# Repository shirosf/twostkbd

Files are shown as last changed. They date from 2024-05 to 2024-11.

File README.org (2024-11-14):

* Two-stroke single hand keyboard
** Introduction
This is a following project to [[https://github.com/shirosf/binarykbd][Binary5 keyboard]]
The basic idea of this keyboard is as follows:
+ hit one of 6 keys twice: 36 codes
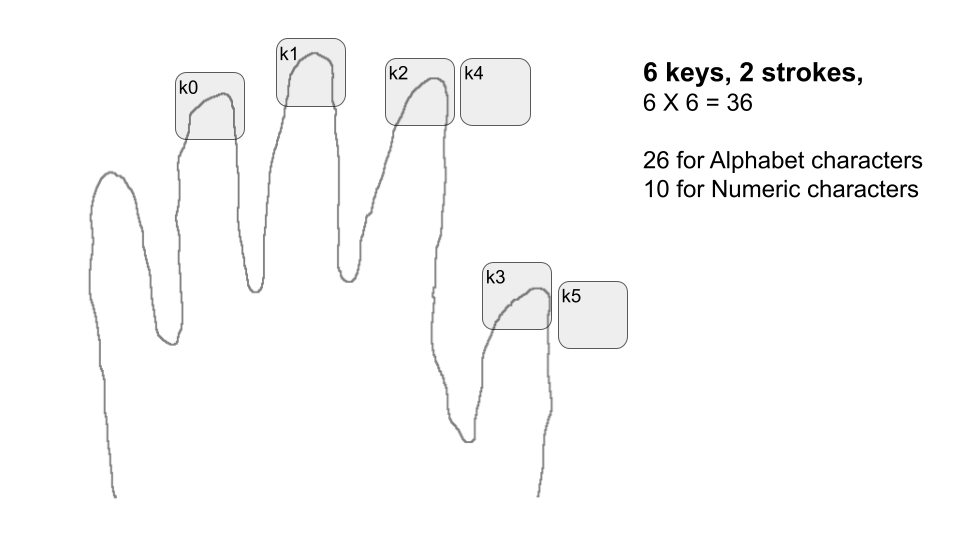
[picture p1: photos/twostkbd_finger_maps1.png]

+ 4 modifiers: 'shift','ctrl','alt', and one more 'ext'
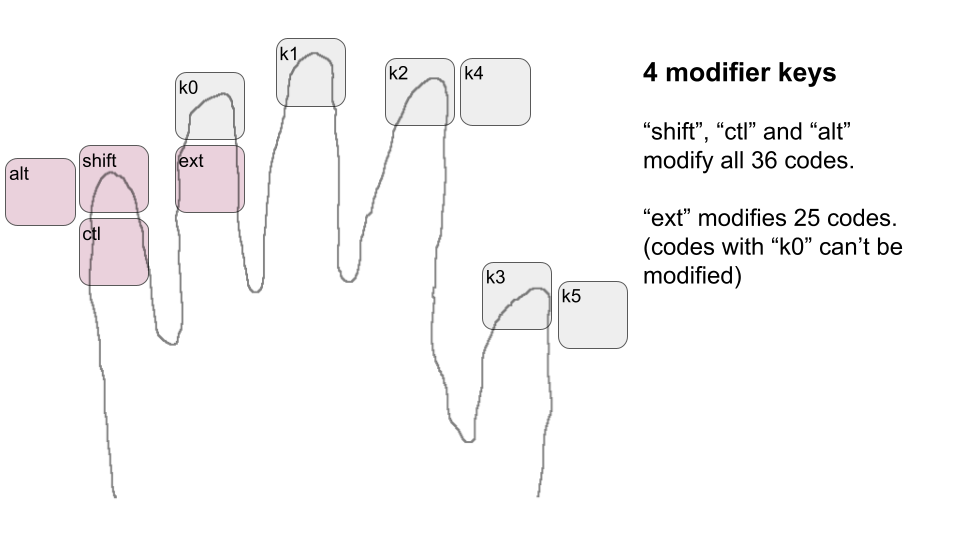
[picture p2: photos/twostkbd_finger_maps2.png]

+ 3 function keys: 'SPACE','BACK SPACE','RETERN'
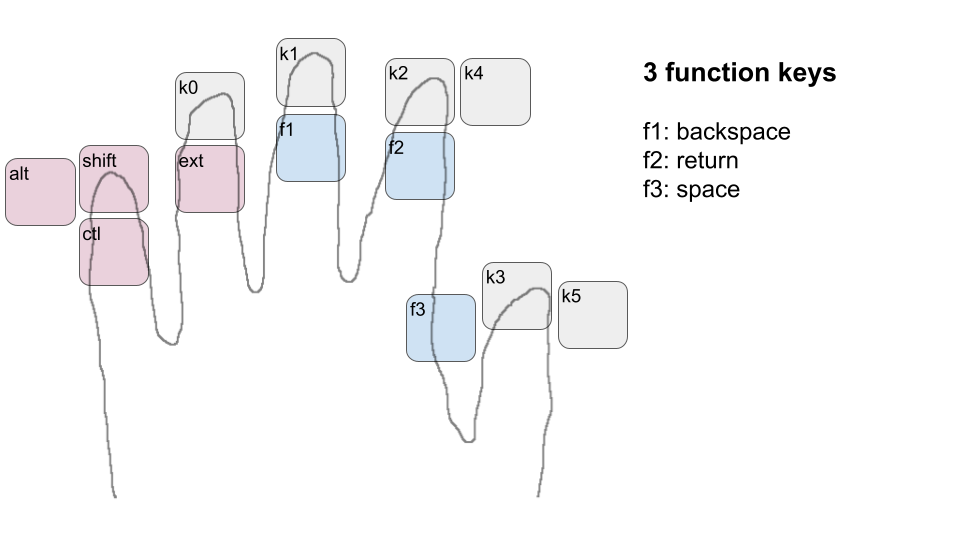
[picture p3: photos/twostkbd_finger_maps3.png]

All key maps can be changed by a configuration file

The total uses 13 keys.
26 of the 36 codes are used for alphabet character codes.
The other 10 are used for numerical character codes.
'ext' modifiers support symbol character codes.

** Hardware
KiCAD schematic and PCB data are in 'pcb' directory.
The HW consists of key switches, LEDs and Raspberry Pi Zero.
The circuits are mostly simple connections between GPIOs and switches.
#+ATTR_LATEX: :width 200px
#+ATTR_HTML: :width 200px
#+CAPTION: 14 keys and Raspberry Pi Zero
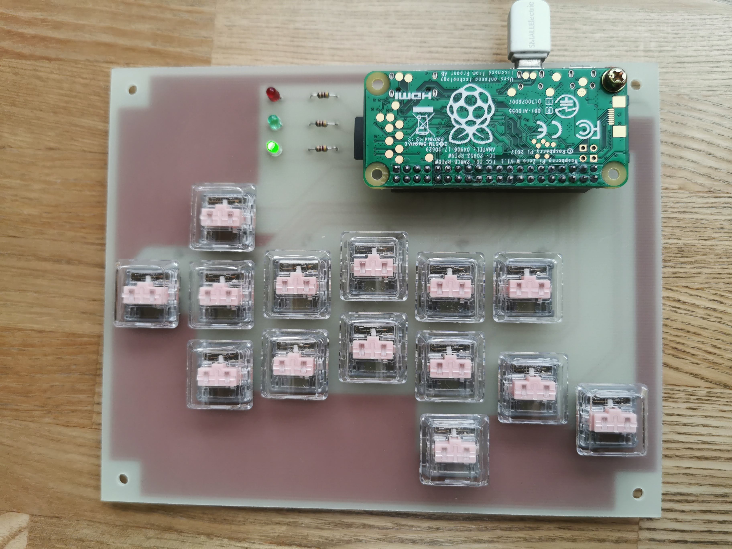
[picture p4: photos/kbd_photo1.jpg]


<2024-09-13 Fri>
Supported "Arduino Nano ESP32" to attach on PiZero connector.
#+ATTR_LATEX: :width 200px
#+ATTR_HTML: :width 200px
#+CAPTION: 13 keys and Arduin Nano ESP32
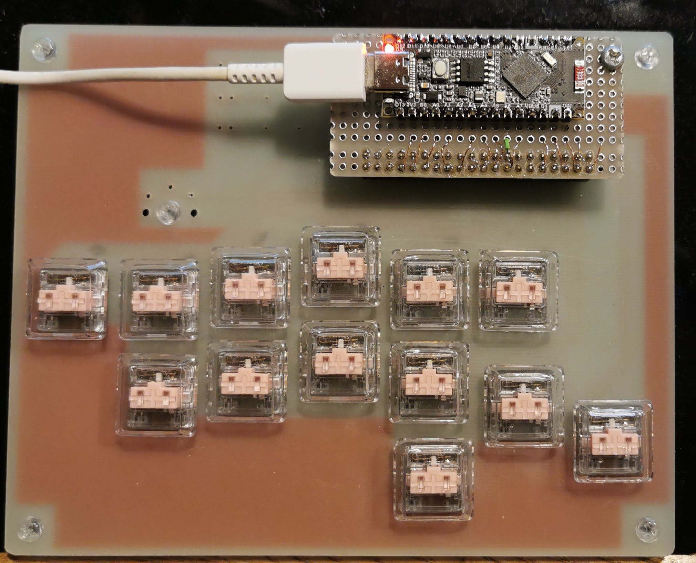
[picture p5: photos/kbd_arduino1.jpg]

It would be better to have both PiZero connector and Arduino Nano
connector on the PCB.
I would update the PCB design at the time of the next PCB order.
Arduino GBIO connections are defined in "key-gpio table" in "config.org"

** Arduino Software
Arduino project directory is "twskbino".
Go to the directory, then edit "Makefile" there to adjust to your hardware.
My Arduino board was an unofficial "esp32-s3" type board; to find out
"FBQN", I chose a looks-close one.
I believe that as long as it is "esp32-s3" type board "FBQN" should be okay.

To build and install from that Makefile, you need to install "arduino-cli"
and "esp32-s3" library.
Once they are ready, "make install" does all the jobs.

People who use IDE need a different way.

The way of configuration is the same as the PiZero Software.
Everything is defined in "config.org".

Arduino Nano has a RGB-LED on the board.
It starts with non-lighting status(R, G, B are all turned off).
'B' is ON when a key is pressed.
'G' is ON when any modifier key is pressed or locked.

** PiZero Software
*** Installation
Copy following 3 files into some directory of Pi Zero.
+ twostkbd.py, create_device.sh, config.org

Using included Makefile, "make sshcopy" copies the files by 'scp'.
It needs 'pizero' defined in ssh config.

*** Run
You go to the directory of the target Pi Zero where 3 files above are copied
by ssh or a local terminal.

At the first time after booting up, 'create_device.sh' needs to be run.
It creates a USB HID device: '/dev/hidg0'.

Once the USB HID device is created, 'twostkbd.py' can run, and it feeds
keyboard events into the device.

*** systemd service
To make the program start automatically at boot time, install "twostkbd.service"
and enable it as follows:
when you copy "twostkbd.py, create_device.sh, config.org" to the target Pi Zero,
you also copy "Makefile, twostkbd.service". Then go to the directory, and run the
following commands:
$ sudo make install
$ sudo make enable_service

When you changed the program or the config file in the working directory,
$ sudo make install
then restart the service again as next:
$ sudo systemctl restart twostkbd.service

*** Configuration
'twostkbd.py' reads 'config.org' file in the working directory.
'config.org' has the following 4 sections:
+ key-gpio table
  Each row defines,
  "schematic switch symbol","GPIO number","key name in this config file"
  Any key switch position can be changed in this table.
  E.G. swapping 'ctrl' and 'shift' in the table swaps the positions of 'ctrl' key
  and 'shift' key.

+ 6-key table
  Each row defines,
  assigned key: alphabet or number.
  '1st key' and '2nd key' combination by number, which is the number part of 'k*' name.
  modified key by the modifier key.
  The most of 'shift', 'alt', 'ctrl' modifier positions are empty.  In those cases the
  modifiers simply add the named modifier bits on the key events.

+ fkey table
  This table defines the function keys: f0 to f3.

+ multikeys table
  When more than 2 keys are pressed at the same time, it functions as "func" column
  defined function.

** License
Unless otherwise explicitly stated,
all files in this project are released under GNU General Public License Version 2.

** Development history
*** <2024-11-15 Fri>
With a half year practice, I come to around 25-WPM level.
And it seems to be saturated and the progress from this point will be very slow.
For some purposes, this keyboard could be useful.
But for my use, which is mostly writing program codes, it can't replace
regular 2-handed keyboards.

I stop this project at this point.

*** <2024-09-14 Sat>
+ Released the Arduino ESP32-S3 software.
PiZero runs a heavy Linux kernel and takes a long time to boot up.
There must be a room to improve by optimization, but I thought it
wouldn't come to my expected level.
With Arduino HW, connecting a USB cable, it becomes ready to use in a second.
Arduino supports a very convenient USBHIDKeyboard library; thanks to it
developing the software was easy.

+ Created a new board which uses "[[http://www.kailh.com/en/Products/Ks/CS/][Kailh Choc Switch]], Red".
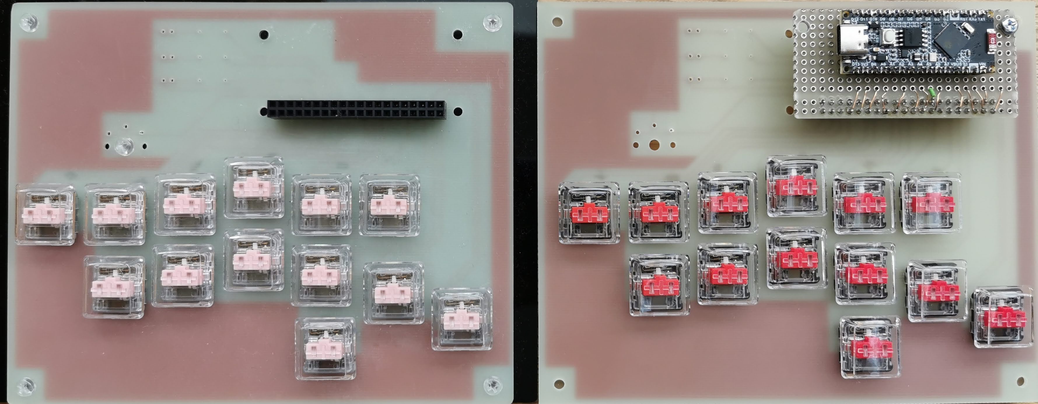
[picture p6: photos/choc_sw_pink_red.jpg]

I've been using "Pink" with 20g operation force.
It was the lightest operation force in what I could find in the market.
Actuary it is a little too light, and I often hit wrong keys inadvertently.
"Red" with 50g is better for that point.
Pursuing faster typing, however, "Pink" would be better.
I'm still wondering which I should use.

*** <2024-08-03 Sat>
Moved TAB to "multikeys table". "k1,k2,k3" is easier than "shift-f2".
"fkey table" modifier functions are all empty, modifier keys are applied on the all.
Changed MULTIKEY_GAP to 50msec from 30msec.

*** <2024-08-02 Fri>
Changed "multikeys table", "up" and "down" are swapped.

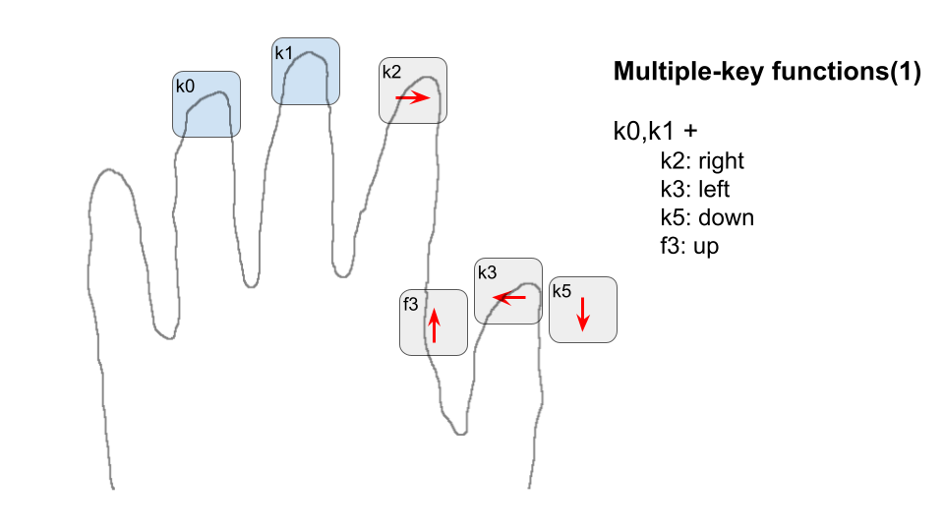
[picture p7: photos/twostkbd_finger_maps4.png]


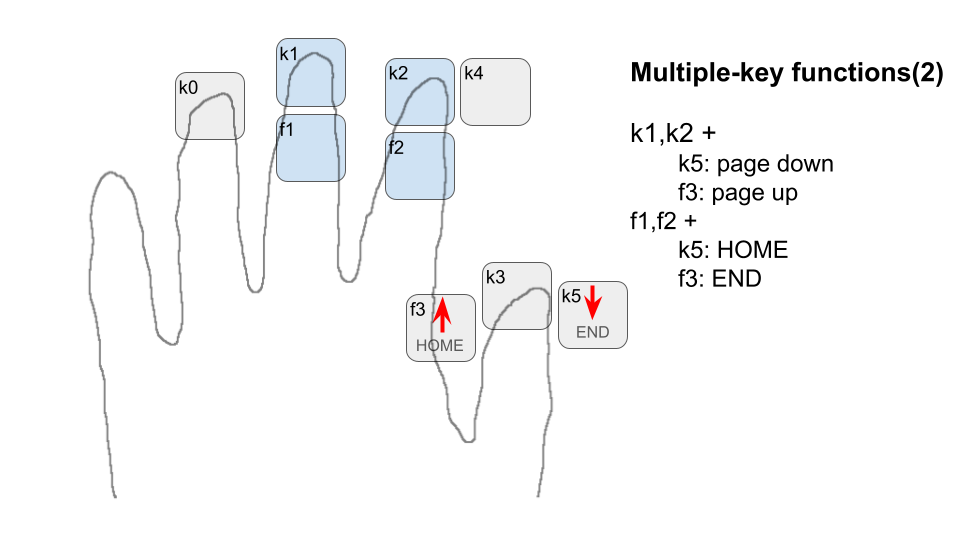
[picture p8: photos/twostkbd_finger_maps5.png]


*** <2024-08-01 Thu>
Refactored the code.
Using "keyqueue", removed multiple timers.
Using "bounce_time" to create Button object, removed the chattering cancellation process.

*** <2024-07-21 Sun>
Tuned "multikeys table" to be convenient for cursor moves.

*** <2024-07-18 Thu>
Removed "fmode table", added "multikeys table" instead.

*** <2024-06-30 Sun>
Published [[https://youtu.be/tp5e6nVgrqI][Youtube Video]].

*** <2024-06-17 Mon>
Modifier keys are difficult to keep holding, especially ALT key.
For a solution, make hitting a modifier key be a locked status for the following
character input.
E.G.
1. hit ALT and release, this locks ALT status
2. input 'x', this becomes ALT-x, and the modifier lock status is released.
When a modifier key is held pressed and a character input happens, the modifier key
is not locked.

*** <2024-06-01 Sat>
Send modifier key events without character key events, so that 'Alt' + 'Mouse click'
type actions can work.

*** <2024-05-25 Sat>
'f0' key is difficult to press. I removed it.
Now, the function keys are 3: 'f1', 'f2' and 'f3'.
'TAB' function is covered by 'shift'+'f2'.

*** <2024-05-14 Tue>
The program basically works okay.
I started practice.

*** <2024-05-10 Fri>
Received PCB

#+OPTIONS: \n:t ^:nil

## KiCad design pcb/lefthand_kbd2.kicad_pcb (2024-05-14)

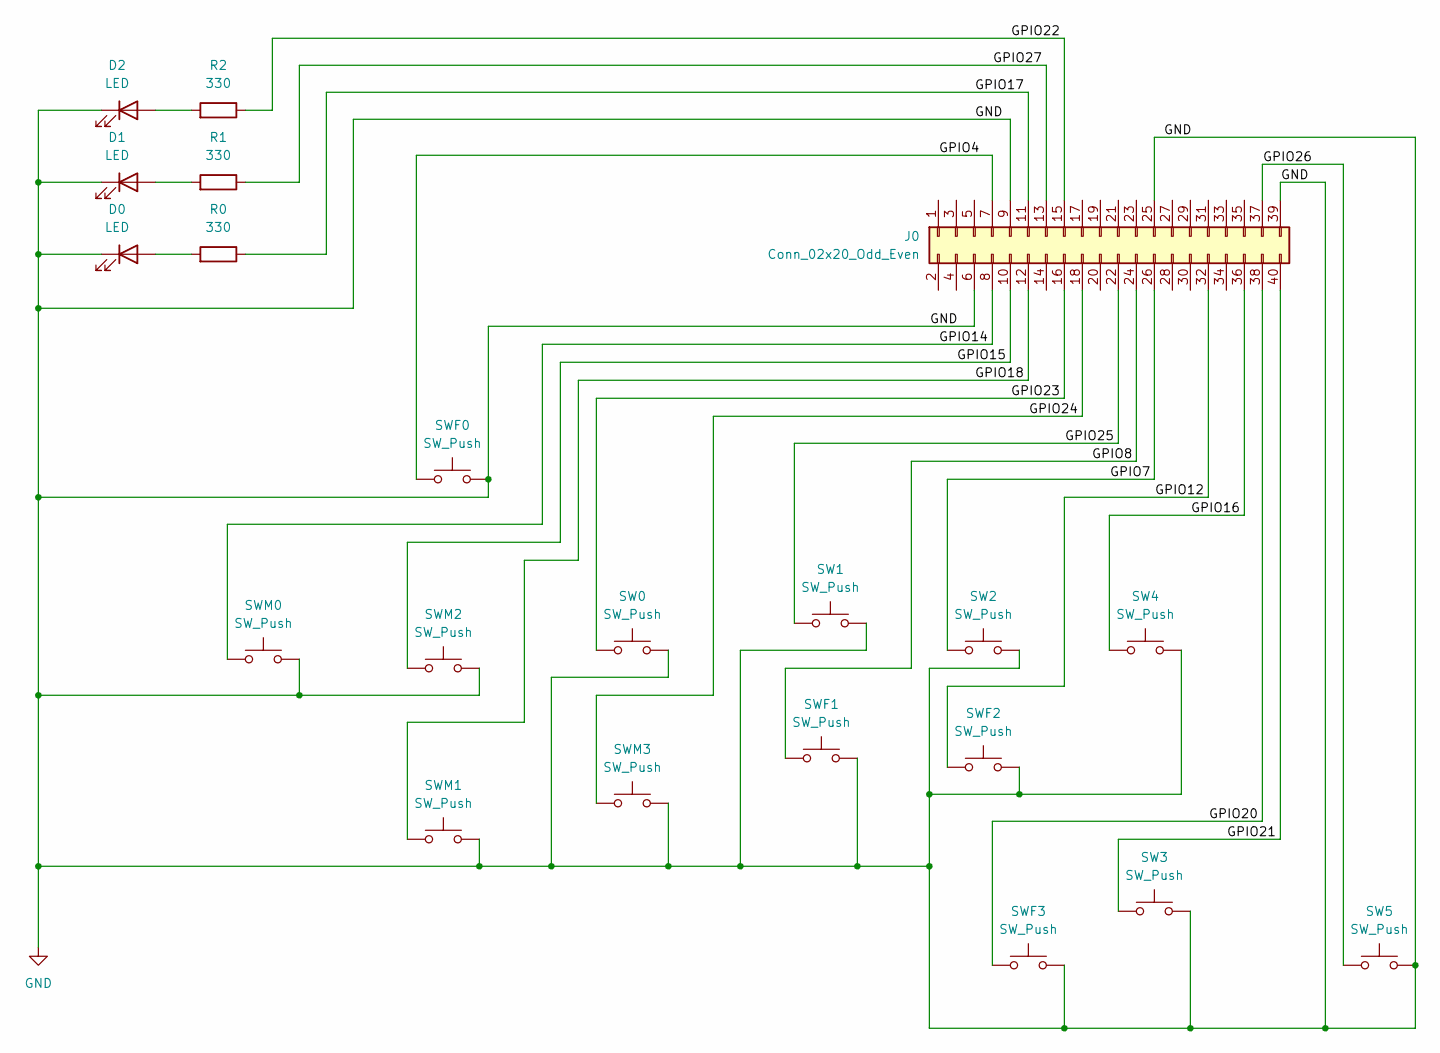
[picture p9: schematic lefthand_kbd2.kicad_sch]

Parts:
D0, D1, D2: LED; D_T-1_P2.54mm_Vertical_AnodeUp
J0: Conn_02x20_Odd_Even; Raspberry_Pi_Zero_Socketed_THT_FaceDown_MountingHoles
R0, R1, R2: 330; R_Axial_DIN0204_L3.6mm_D1.6mm_P7.62mm_Horizontal
SW0, SW1, SW2, SW3, SW4, SW5: SW_Push; Kailh_Choc
SWF0, SWF1, SWF2, SWF3: SW_Push; Kailh_Choc
SWM0, SWM1, SWM2, SWM3: SW_Push; Kailh_Choc

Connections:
/GPIO4: J0.7, SWF0.1
/GPIO7: J0.26, SW2.1
/GPIO8: J0.24, SWF1.1
/GPIO12: J0.32, SWF2.1
/GPIO14: J0.8, SWM0.1
/GPIO15: J0.10, SWM2.1
/GPIO16: J0.36, SW4.1
/GPIO17: J0.11, R0.1
/GPIO18: J0.12, SWM1.1
/GPIO20: J0.38, SWF3.1
/GPIO21: J0.40, SW3.1
/GPIO22: J0.15, R2.1
/GPIO23: J0.16, SW0.1
/GPIO24: J0.18, SWM3.1
/GPIO25: J0.22, SW1.1
/GPIO26: J0.37, SW5.1
/GPIO27: J0.13, R1.1
GND: D0.1 (K), D1.1 (K), D2.1 (K), J0.6, J0.9, J0.25, J0.39, SW0.2, SW1.2, SW2.2, SW3.2, SW4.2, SW5.2, SWF0.2, SWF1.2, SWF2.2, SWF3.2, SWM0.2, SWM1.2, SWM2.2, SWM3.2
unnamed: D0.2 (A), R0.2
unnamed: D1.2 (A), R1.2
unnamed: D2.2 (A), R2.2

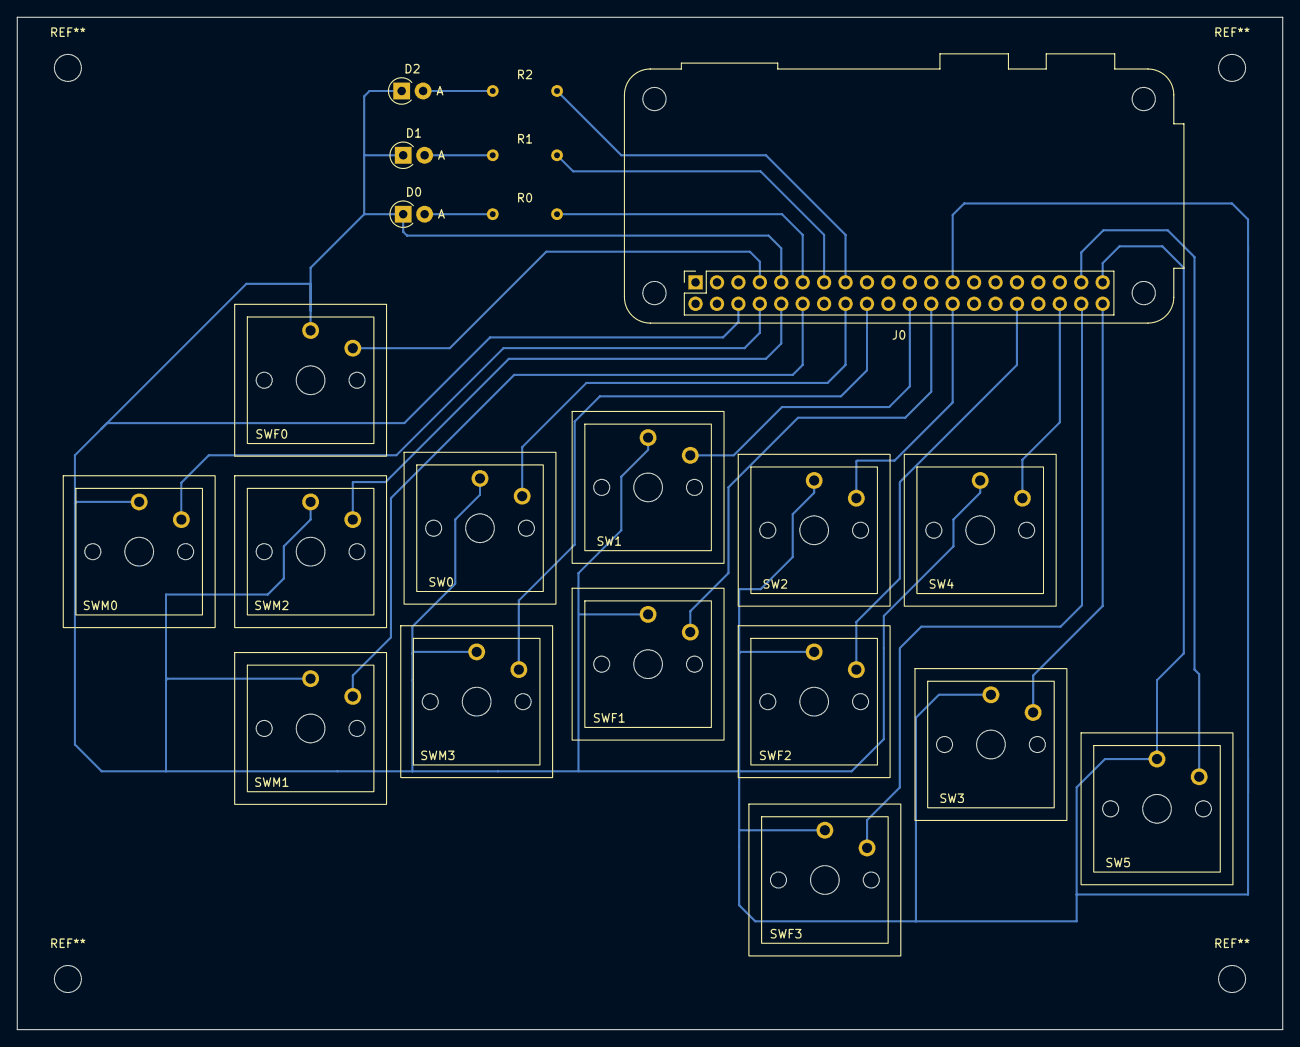
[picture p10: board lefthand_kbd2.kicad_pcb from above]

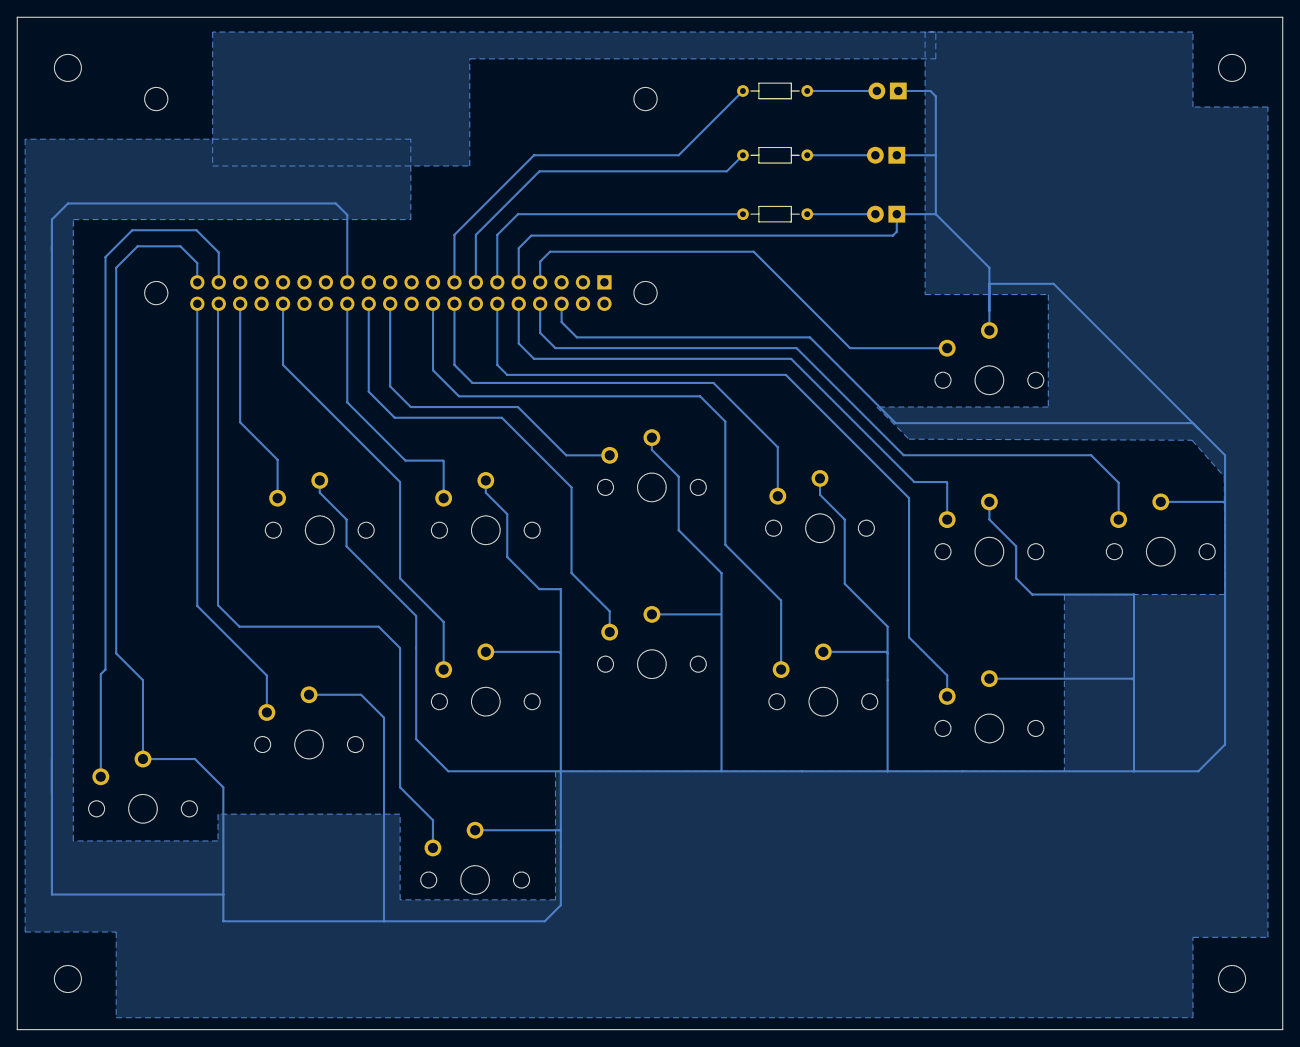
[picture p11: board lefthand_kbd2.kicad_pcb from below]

Board: 2 copper layers, 150.0 x 120.0 mm, 21 parts (3 on the bottom side), 21 nets.

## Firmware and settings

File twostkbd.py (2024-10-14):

#!/usr/bin/env python3
# -*- coding: utf-8 -*-
#
# Copyright (C) 2024 Shiro Ninomiya
#
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
import logging
import time
import threading
try:
    from gpiozero import Button, LED
except:
    print("not running on PiZero")

logger=logging.getLogger('twostkbd')
logger.setLevel(logging.DEBUG)

class KbdConfig():
    flabels=("alt","ctrl","shift","ext","k0","k1","k2","k3","k4","k5","f0","f1","f2","f3")
    mnames=("shift", "alt", "ctrl", "ext")
    def get_keygpio_table(self, items):
        if len(items)<5: return 0
        try:
            kname=items[1].strip()
            if kname=="kname": return 0
            gpn=int(items[2])
            if gpn<0 or gpn>27: raise ValueError
            self.btgpios[kname]=gpn
            self.argpios[kname]=items[3].strip()
        except ValueError:
            logger.error("gpio msut be a number in 0 to 27, %s" % str(items))
            return -1
        return 0

    def get_skey_table(self, items):
        if len(items)<10: return 0
        try:
            item1=items[1].strip()
            if item1=="": return 0
            if item1=='No.': return 0
            index=int(item1)
            if index<0 or index>35: raise ValueError
        except ValueError:
            logger.error("'No.' item msut be a number in 0 to 35")
            return -1
        try:
            key=items[2].strip()
            firstkey=items[3].strip()
            secondkey=items[4].strip()
            mkeys={}
            for i in range(4):
                mkeys[self.mnames[i]]=items[5+i].strip()
        except:
            logger.error("invalid value in 6-key table")
            return -1
        self.skeytable[index]={"key":key, "1st":firstkey, "2nd":secondkey, "mkeys":mkeys}
        return 0

    def get_fkey_table(self, items):
        if len(items)<8: return 0
        try:
            item1=items[1].strip()
            if item1=="": return 0
            if item1=='f.key': return 0
            index=int(item1)
            if index<0 or index>3: raise ValueError
        except ValueError:
            logger.error("'f.key' item msut be a number in 0 to 3")
            return -1
        try:
            func=items[2].strip()
            mfuncs={}
            for i in range(4):
                mfuncs[self.mnames[i]]=items[3+i].strip()
        except:
            logger.error("invalid value in fkey table")
            return -1
        self.fkeytable[index]={"func":func, "mfuncs":mfuncs}
        return 0

    def get_multikeys_table(self, items):
        if len(items)<4: return 0
        item1=items[1].strip()
        if item1=="": return 0
        if item1=='func': return 0
        multikeys=items[2].strip().split(",")
        v=0
        for mk in multikeys:
            v|=1<<self.btgpios[mk]
        self.multikeystable[v]=item1
        self.mkeytable.append([item1]+multikeys)
        return 0

    def readconf(self, conffile: str="config.org") -> int:
        inf=open(conffile, "r")
        state=0
        self.skeytable=[None]*36
        self.fkeytable=[None]*4
        self.multikeystable={}
        self.mkeytable=[]
        self.btgpios={}
        self.argpios={}
        while True:
            keydef={}
            line=inf.readline()
            if line=='': break
            if state==0:
                if line.find("key-gpio table")>0:
                    state=1
                if line.find("6-key table")>0:
                    state=2
                if line.find("fkey table")>0:
                    state=3
                if line.find("multikeys table")>0:
                    state=4
                continue
            if line[0]!='|':
                state=0
                continue
            items=line.split('|')
            if state==1:
                if self.get_keygpio_table(items)!=0: return -1
            if state==2:
                if self.get_skey_table(items)!=0: return -1
            if state==3:
                if self.get_fkey_table(items)!=0: return -1
            if state==4:
                if self.get_multikeys_table(items)!=0: return -1
        inf.close()
        return 0

class KbdDevice():
    BOUNCE_GUARD_SEC=0.01
    MULTIKEY_GAP_NS=50000000
    def __init__(self):
        self.config=KbdConfig()
        if self.config.readconf()!=0:
            logger.error("can't read 'config.org'")
            return
        self.buttons={}
        ledgpios={"LED0":17, "LED1":27, "LED2":22}
        self.leds={"LED0":None, "LED1":None, "LED2":None}
        tsns=time.time_ns()
        for l in self.config.btgpios.keys():
            bt=Button(self.config.btgpios[l], bounce_time=KbdDevice.BOUNCE_GUARD_SEC)
            self.buttons[bt]={"kname":l, "ts":time.time_ns(), "state":0, "ontimer":None,
                              "offtimer":None}
            bt.when_pressed=self.on_pressed
            bt.when_released=self.on_released
        for l in self.leds.keys():
            self.leds[l]=LED(ledgpios[l])
        self.multikey_timer=None
        self.multikey_pressedv=0
        self.modkeys={"shift":False, "alt":False, "ctrl":False, "ext":False}
        self.modkeys_lock={"shift":False, "alt":False, "ctrl":False, "ext":False}
        self.leds["LED0"].on()
        self.modifiers={'RightGUI':(1<<7), 'RightAlt':(1<<6), 'RightShift':(1<<5),
                        'RightCtl':(1<<4), 'LeftGui':(1<<3), 'LeftAlt':(1<<2),
                        'LeftShift':(1<<1), 'LeftCtr':(1<<0)}
        self.devicefd=open("/dev/hidg0", "w")
        self.print_skeytable()
        self.keyqueue=[]
        self.last_write=None

    def print_skeytable(self):
        fhelp={"0":"r ","1":"m ", "2":"i ", "3":"t ", "4":"ir", "5":"tr"}
        for sk in self.config.skeytable:
            skm0=sk["mkeys"]["shift"]
            if not skm0:
                skm0=sk["key"].upper()
            elif skm0=="VBAR":
                skm0="|"
            print("%s(%s)-%s(%s): %s, %s, %s" % ( sk["1st"], fhelp[sk["1st"]],
                                                  sk["2nd"], fhelp[sk["2nd"]],
                                                  sk["key"], skm0, sk["mkeys"]["ext"]))

    def close(self):
        self.devicefd.close()
        for bt in self.buttons.keys():
            bt.close()
        for led in self.leds.values():
            led.close()

    def scancode(self, key: str, nomod: bool = False) -> tuple[int, int]:
        scodes={
            '0':(0x27,0,0),
            'RET':(0x28,0,0),
            'ESC':(0x29,0,0),
            'BS':(0x2a,0,0),
            'TAB':(0x2b,0,0),
            'SP':(0x2c,0,0),
            '-':(0x2d,0,0),
            '=':(0x2e,0,0),
            '[':(0x2f,0,0),
            ']':(0x30,0,0),
            '\\':(0x31,0,0),
            ';':(0x33,0,0),
            "'":(0x34,0,0),
            '`':(0x35,0,0),
            ',':(0x36,0,0),
            '.':(0x37,0,0),
            '/':(0x38,0,0),
            'F1':(0x3a,0,0),
            'F2':(0x3b,0,0),
            'F3':(0x3c,0,0),
            'F4':(0x3d,0,0),
            'F5':(0x3e,0,0),
            'F6':(0x3f,0,0),
            'F7':(0x40,0,0),
            'F8':(0x41,0,0),
            'F9':(0x42,0,0),
            'F10':(0x43,0,0),
            'F11':(0x44,0,0),
            'F12':(0x45,0,0),
            'HOME':(0x4a,0,self.modifiers['LeftCtr']),
            'PUP':(0x4b,0,self.modifiers['LeftAlt']),
            'DEL':(0x4c,0,self.modifiers['LeftCtr']),
            'CSDEL':(0x4c,self.modifiers['LeftShift']|self.modifiers['LeftCtr'],0),
            'END':(0x4d,0,self.modifiers['LeftCtr']),
            'PDOWN':(0x4e,0,self.modifiers['LeftCtr']),
            'RIGHT':(0x4f,0,self.modifiers['LeftCtr']),
            'CRIGHT':(0x4f,self.modifiers['LeftCtr'],self.modifiers['LeftAlt']),
            'LEFT':(0x50,0,self.modifiers['LeftCtr']),
            'CLEFT':(0x50,self.modifiers['LeftCtr'],self.modifiers['LeftAlt']),
            'DOWN':(0x51,0,self.modifiers['LeftCtr']),
            'UP':(0x52,0,self.modifiers['LeftCtr']),
            'COPY':(ord('c')-ord('a')+4,self.modifiers['LeftCtr'],0),
            'PASTE':(ord('v')-ord('a')+4,self.modifiers['LeftCtr'],0),
            'CHOME':(0x4a,self.modifiers['LeftCtr'],0),
            'CEND':(0x4d,self.modifiers['LeftCtr'],0),
            'CTAB':(0x2b,self.modifiers['LeftCtr'],0),
            'SSP':(0x2c,self.modifiers['LeftShift'],0),
            'SRET':(0x28,self.modifiers['LeftShift'],0),
            'SBS':(0x2a,self.modifiers['LeftShift'],0),
            'STAB':(0x2b,self.modifiers['LeftShift'],0),
            'CTLX':(ord('x')-ord('a')+0x04,self.modifiers['LeftCtr'],0),
            'CTLC':(ord('c')-ord('a')+0x04,self.modifiers['LeftCtr'],0),
            'CTLV':(ord('v')-ord('a')+0x04,self.modifiers['LeftCtr'],0),
            'CTLF':(ord('f')-ord('a')+0x04,self.modifiers['LeftCtr'],0),
            'CTLY':(ord('y')-ord('a')+0x04,self.modifiers['LeftCtr'],0),
            'CTLZ':(ord('z')-ord('a')+0x04,self.modifiers['LeftCtr'],0),
            'CTLG':(ord('g')-ord('a')+0x04,self.modifiers['LeftCtr'],0),
            'CTL/':(0x38,self.modifiers['LeftCtr'],0),
            'ALTX':(ord('x')-ord('a')+0x04,self.modifiers['LeftAlt'],0),
            'ALTW':(ord('w')-ord('a')+0x04,self.modifiers['LeftAlt'],0),
            '!':(0x1e,self.modifiers['LeftShift'],0),
            '@':(0x1f,self.modifiers['LeftShift'],0),
            '#':(0x20,self.modifiers['LeftShift'],0),
            '$':(0x21,self.modifiers['LeftShift'],0),
            '%':(0x22,self.modifiers['LeftShift'],0),
            '^':(0x23,self.modifiers['LeftShift'],0),
            '*':(0x25,self.modifiers['LeftShift'],0),
            '&':(0x24,self.modifiers['LeftShift'],0),
            '(':(0x26,self.modifiers['LeftShift'],0),
            ')':(0x27,self.modifiers['LeftShift'],0),
            '_':(0x2d,self.modifiers['LeftShift'],0),
            '+':(0x2e,self.modifiers['LeftShift'],0),
            '{':(0x2f,self.modifiers['LeftShift'],0),
            '}':(0x30,self.modifiers['LeftShift'],0),
            'VBAR':(0x32,self.modifiers['LeftShift'],0),
            ':':(0x33,self.modifiers['LeftShift'],0),
            '"':(0x34,self.modifiers['LeftShift'],0),
            '~':(0x35,self.modifiers['LeftShift'],0),
            '<':(0x36,self.modifiers['LeftShift'],0),
            '>':(0x37,self.modifiers['LeftShift'],0),
            '?':(0x38,self.modifiers['LeftShift'],0),
        }

        mbits=0
        if not nomod:
            if self.modkeys["shift"]:
                mbits|=self.modifiers['LeftShift']
            if self.modkeys["alt"]:
                mbits|=self.modifiers['LeftAlt']
            if self.modkeys["ctrl"]:
                mbits|=self.modifiers['LeftCtr']

        if len(key)==1:
            if key>='a' and key<='z':
                return (ord(key)-ord('a')+0x04, mbits)
            if key>='1' and key<='9':
                return (ord(key)-ord('1')+0x1e, mbits)
        elif len(key)==0:
            return (0, mbits)

        mbits|=scodes[key][1]
        mbits&=~scodes[key][2]
        return (scodes[key][0], mbits)

    def on_pressed(self, bt) -> None:
        if self.multikey_timer: self.multikey_timer.cancel()
        self.multikey_timer=None
        tsns=time.time_ns()
        self.keyqueue.append((bt,tsns))
        self.leds["LED1"].on()
        if self.proc_keyqueue(): return
        self.multikey_timer=threading.Timer(KbdDevice.MULTIKEY_GAP_NS/1E9,
                                            self.proc_multikey_timer)
        self.multikey_timer.start()

    def proc_multikey_timer(self):
        tsns=time.time_ns()
        self.keyqueue.append((None,tsns))
        self.proc_keyqueue()

    # return True when the next press must follow after this
    def proc_keyqueue(self) -> bool:
        res=True
        ki=0
        self.holding_2keys=False
        while(len(self.keyqueue)>ki):
            bt,tsns=self.keyqueue[ki]
            if bt==None:
                ki=self.proc_gapnext(ki)
                res=True
                continue
            kname=self.buttons[bt]["kname"]
            if len(kname)>2:
                # pushed key is a mod key
                self.on_mod_pressed(bt, kname)
                self.keyqueue.pop(ki)
                res=True
                continue
            if ki==0 or self.check_possible_multikeys(ki+1)!=0:
                # "queue top" or "more keys can be expected". go next in the queue
                res=False
                ki+=1
                continue
            # process upto this key in the queue.
            self.proc_stroks(ki+1)
            self.holding_2keys=False
            ki=0
            res=True
        return res

    # get this when Timer expired "None key" come to the queue top.
    # it means the time gap exists keys beofre this "None key"
    def proc_gapnext(self, ki: int):
        self.keyqueue.pop(ki)
        if ki==2:
            dts=self.keyqueue[1][1]-self.keyqueue[0][1]
            if dts<KbdDevice.MULTIKEY_GAP_NS:
                if self.check_possible_multikeys(ki)!=0:
                    # holding 2 keys, 3rd key may be coming. Wait a next key.
                    self.holding_2keys=True
                    return ki
        if ki>1:
            self.proc_stroks(ki) # multiple keys with (0 to ki-1), pop inside the function
            self.holding_2keys=False
            return 0
        if ki==1:
            bt0=self.keyqueue[0][0]
            if self.buttons[bt0]["kname"][0]=="f":
                self.proc_stroks(ki) # process a func key
                return 0
        return ki

    def check_possible_multikeys(self, ki: int, exact=False) -> int:
        if ki==0:
            if self.keyqueue[0][0]["kname"][0]=="k": return 1
            # it must be "f" key
            return 0
        # check with multikeystable
        mkbits=0
        skip_zero=self.keyqueue[1][1]-self.keyqueue[0][1] > \
            KbdDevice.MULTIKEY_GAP_NS
        for i,(bt,tsns) in enumerate(self.keyqueue):
            if i==ki: break
            if bt==None: continue
            if i==0 and skip_zero: continue
            kname=self.buttons[bt]["kname"]
            kbit=1<<self.config.btgpios[kname]
            if ki==2 and mkbits==kbit:
                # the same key twice
                return 0
            mkbits|=kbit
        for mkv in self.config.multikeystable.keys():
            if exact:
                if mkv == mkbits:
                    if skip_zero: self.keyqueue.pop(0)
                    return mkv
            else:
                if (mkbits & mkv) == mkbits: return 1
        return 0

    def proc_stroks(self, ki: int) -> None:
        rk0=None
        if ki>2:
            mkv=self.check_possible_multikeys(ki, exact=True)
            if not mkv:
                for i in range(ki): self.keyqueue.pop(0)
                self.multikey_pressedv=0
                return
            self.on_multikeys_pressed(mkv)
            return
        or_pressed=False
        for i in range(ki):
            bt, tsns=self.keyqueue.pop(0)
            or_pressed|=bt.is_pressed
            kname=self.buttons[bt]["kname"]
            if kname[0]=="f":
                if rk0!=None:
                    # "f" comes after the first "k". It is a cancel signal
                    rk0=None
                    continue
                self.on_fkey_pressed(bt, kname)
                if not or_pressed: self.clear_devicefd()
                continue
            if kname[0]=="k":
                if rk0!=None:
                    self.on_rkey_pressed(rk0, bt)
                    if not or_pressed: self.clear_devicefd()
                    rk0=None
                    continue
                rk0=bt
                continue

    def on_mod_pressed(self, bt, kname: str) -> None:
        if self.modkeys_lock[kname]:
            self.modkeys_lock[kname]=False
            return
        self.modkeys_lock[kname]=True
        self.leds["LED2"].on()
        self.modkeys[kname]=True
        self.hidevent_pressed(kname, "mod")

    def on_fkey_pressed(self, bt, kname: str) -> None:
        self.hidevent_pressed(kname, "func")

    def on_rkey_pressed(self, bt0, bt) -> None:
        kname0=self.buttons[bt0]["kname"]
        kname=self.buttons[bt]["kname"]
        self.hidevent_pressed(kname, "reg", kname0)

    def on_multikeys_pressed(self, mkv:int) -> None:
        kname=self.config.multikeystable[mkv]
        self.hidevent_pressed(kname, "mult")
        self.multikey_pressedv=mkv

    def hidevent_pressed(self, kname: str, mode: str, kname0: str = 0):
        scode=bytearray(b"\0\0\0\0\0\0\0\0")
        if mode=="reg":
            inkey=self.inkey_rk(kname0[1], kname[1])
            self.modkeys_unlock()
        elif mode=="mod":
            inkey=self.scancode('')
        elif mode=="func":
            inkey=self.inkey_fkey(kname[1])
            self.modkeys_unlock()
        elif mode=="mult":
            # only "TAB" uses modifiers
            nomod=False if kname=="TAB" else True
            inkey=self.scancode(kname, nomod=nomod)
            self.modkeys_unlock()
        else:
            return
        if inkey==None: return
        scode[0]=inkey[1]
        scode[2]=inkey[0]
        self.last_write=scode.decode("utf-8")
        self.devicefd.write(self.last_write)
        self.devicefd.flush()

    def inkey_rk(self, kn1, kn2):
        for i in range(36):
            sktable=self.config.skeytable[i]
            if sktable["1st"]!=kn1 or \
               sktable["2nd"]!=kn2:
                continue
            logger.debug("press %s,%d,%d,%d,%d" % (sktable["key"],
                                                   self.modkeys["shift"],self.modkeys["alt"],
                                                   self.modkeys["ctrl"],self.modkeys["ext"]))
            if self.modkeys["ext"] and sktable["mkeys"]["ext"]:
                return self.scancode(sktable["mkeys"]["ext"])
            elif self.modkeys["shift"] and sktable["mkeys"]["shift"]:
                return self.scancode(sktable["mkeys"]["shift"])
            else:
                return self.scancode(sktable["key"])
        else:
            return None

    def inkey_fkey(self, kn):
        fktable=self.config.fkeytable[int(kn)]
        nomod=False
        for mn in KbdConfig.mnames:
            if self.modkeys[mn]:
                fk=fktable["mfuncs"][mn]
                if fk:
                    nomod=True
                    break
        else:
            fk=fktable["func"]
        if not fk: return None
        logger.debug("press %s,%d,%d,%d,%d" % (fk,
                                               self.modkeys["shift"],self.modkeys["alt"],
                                               self.modkeys["ctrl"],self.modkeys["ext"]))
        return self.scancode(fk, nomod=nomod)

    def all_modkeys_off(self) -> bool:
        return not (self.modkeys["shift"] or self.modkeys["alt"] or \
                    self.modkeys["ctrl"] or self.modkeys["ext"])

    def modkeys_unlock(self) -> None:
        for bt,btv in self.buttons.items():
            if btv["kname"][0]=='k' or btv["kname"][0]=='f': continue
            if self.modkeys_lock[btv["kname"]]:
                self.modkeys_lock[btv["kname"]]=False
                if not bt.is_pressed:
                    self.modkeys[btv["kname"]]=False
                    if self.all_modkeys_off(): self.leds["LED2"].off()

    def on_released(self, bt) -> None:
        kname=self.buttons[bt]["kname"]
        if self.multikey_pressedv!=0:
            self.clear_multikey_in_queue(kname)
            return self.clear_devicefd()
        if len(kname)>2:
            # release a mod key
            if self.modkeys_lock[kname]: return
            self.modkeys_unlock()
            self.modkeys[kname]=False
            if self.all_modkeys_off(): self.leds["LED2"].off()
            return self.clear_devicefd()
        if kname[0]=="k":
            # release a regular key
            if self.holding_2keys:
                self.proc_stroks(2)
                self.holding_2keys=False
        return self.clear_devicefd()

    def clear_multikey_in_queue(self, kname) -> None:
        for (bt,tsns) in self.keyqueue:
            qkname=self.buttons[bt]["kname"]
            if kname!=qkname: continue
            self.keyqueue.remove((bt,tsns))
            mkbit=1<<self.config.btgpios[kname]
            self.multikey_pressedv&=~mkbit
            if self.multikey_pressedv==0:
                self.modkeys_unlock()
            return

    def clear_devicefd(self):
        if len(self.keyqueue)==0:
            self.leds["LED1"].off()
        scode=bytearray(b"\0\0\0\0\0\0\0\0")
        inkey_m=self.scancode('')
        scode[0]=inkey_m[1]
        nwd=scode.decode("utf-8")
        if self.last_write!=nwd:
            self.last_write=nwd
            self.devicefd.write(self.last_write)
            self.devicefd.flush()

if __name__ == '__main__':
    kbd = KbdDevice()
    while True:
        try:
            threading.Event().wait()
        except:
            break
    kbd.close()

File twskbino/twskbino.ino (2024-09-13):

#ifndef ARDUINO_USB_MODE
#error This ESP32 SoC has no Native USB interface
#elif ARDUINO_USB_MODE == 1
#warning This sketch should be used when USB is in OTG mode
void setup() {}
void loop() {}
#else

#include "USB.h"
#include "USBHIDKeyboard.h"
#include <soc/gpio_reg.h>
#include "twskb.hpp"

#define LED_RED 46
#define LED_GREEN 0
#define LED_BLUE 45

USBHIDKeyboard Keyboard;


Twskbd *twkd;

struct kbdio_data {
	unsigned char key_gpios[13];
	unsigned char keybit_index[32];
	unsigned long keys_mask;
	unsigned long gpd;
	unsigned long *gpdp;
	unsigned long ugpdp;
};

KbdInOut::KbdInOut(void)
{
	int i;
	unsigned char kbi[13]=KEY_GPIO_LIST;
	kbdiod=(struct kbdio_data*)malloc(sizeof(struct kbdio_data));
	memset(kbdiod, 0, sizeof(struct kbdio_data));
	kbdiod->gpdp=(unsigned long *)GPIO_IN_REG;
	memcpy(kbdiod->key_gpios, kbi, 13);
	memset(kbdiod->keybit_index, 0xff, sizeof(kbdiod->keybit_index));
	for(i=0;i<13;i++){
		pinMode(kbdiod->key_gpios[i], INPUT_PULLUP);
		kbdiod->keys_mask|=(1<<kbdiod->key_gpios[i]);
		kbdiod->keybit_index[kbdiod->key_gpios[i]]=i;
	}
	kbdiod->gpd=*kbdiod->gpdp & kbdiod->keys_mask;
	kbdiod->ugpdp=0;

	pinMode(LED_RED, OUTPUT);
	pinMode(LED_GREEN, OUTPUT);
	pinMode(LED_BLUE, OUTPUT);
	Keyboard.begin();
	USB.begin();
}

KbdInOut::~KbdInOut(void)
{
	free(kbdiod);
}

void KbdInOut::print_kd(KeyFifo::key_fifo_data_t *kd)
{
	char pbuf[4];
	if(kd->pressed){
		sprintf(pbuf, "%d+", kd->ki);
	}else{
		sprintf(pbuf, "%d-", kd->ki);
	}
	Keyboard.print(pbuf);
}

void KbdInOut::set_rgb_led(rgb_color_index_t ci)
{
	digitalWrite(LED_RED, HIGH);
	digitalWrite(LED_GREEN, HIGH);
	digitalWrite(LED_BLUE, HIGH);
	switch(ci){
	case RGB_COLOR_BLACK:
		return;
	case RGB_COLOR_RED:
		digitalWrite(LED_RED, LOW);
		return;
	case RGB_COLOR_GREEN:
		digitalWrite(LED_GREEN, LOW);
		return;
	case RGB_COLOR_BLUE:
		digitalWrite(LED_BLUE, LOW);
		return;
	case RGB_COLOR_YELLOW:
		digitalWrite(LED_RED, LOW);
		digitalWrite(LED_GREEN, LOW);
		return;
	case RGB_COLOR_CYAN:
		digitalWrite(LED_GREEN, LOW);
		digitalWrite(LED_BLUE, LOW);
		return;
	case RGB_COLOR_MAGENTA:
		digitalWrite(LED_RED, LOW);
		digitalWrite(LED_BLUE, LOW);
		return;
	case RGB_COLOR_WHITE:
		digitalWrite(LED_RED, LOW);
		digitalWrite(LED_GREEN, LOW);
		digitalWrite(LED_BLUE, LOW);
		return;
	}
}

void KbdInOut::set_bit_led(rgb_color_index_t ci, bool ledon)
{
	uint8_t val=ledon?LOW:HIGH;
	switch(ci){
	case RGB_COLOR_RED:
		digitalWrite(LED_RED, val);
		return;
	case RGB_COLOR_GREEN:
		digitalWrite(LED_GREEN, val);
		return;
	case RGB_COLOR_BLUE:
		digitalWrite(LED_BLUE, val);
		return;
	default:
		return;
	}
}


bool KbdInOut::get_inkey(KeyFifo::key_indexmap_t *ki, bool *pressed)
{
	unsigned long ngpd;
	unsigned long mb;
	int i;
	if(kbdiod->ugpdp==0){
		ngpd=*kbdiod->gpdp & kbdiod->keys_mask;
		kbdiod->ugpdp=kbdiod->gpd^ngpd; // changed bits in ugpd
		kbdiod->gpd=ngpd;
	}
	if(kbdiod->ugpdp==0){return false;}
	mb=1;
	for(i=0;i<32;i++){
		if((kbdiod->ugpdp & mb) && (kbdiod->keybit_index[i]!=0xff)){
			*pressed=(kbdiod->gpd & mb) != mb;
			*ki=(KeyFifo::key_indexmap_t)kbdiod->keybit_index[i];
			kbdiod->ugpdp&=~mb;
			return true;
		}
		mb=mb<<1;
	}
	return false;
}

void KbdInOut::key_press(uint8_t x)
{
	if(x==KEYCODE_0){return;}
	if(x==KEYCODE_LEFT_CTRL){
		Keyboard.pressRaw(HID_KEY_CONTROL_LEFT);
	}else if(x==KEYCODE_LEFT_SHIFT){
		Keyboard.pressRaw(HID_KEY_SHIFT_LEFT);
	}else if(x==KEYCODE_LEFT_ALT){
		Keyboard.pressRaw(HID_KEY_ALT_LEFT);
	}else{
		Keyboard.press(x);
	}
}

void KbdInOut::key_release(uint8_t x)
{
	if(x==KEYCODE_0){return;}
	if(x==KEYCODE_LEFT_CTRL){
		Keyboard.releaseRaw(HID_KEY_CONTROL_LEFT);
	}else if(x==KEYCODE_LEFT_SHIFT){
		Keyboard.releaseRaw(HID_KEY_SHIFT_LEFT);
	}else if(x==KEYCODE_LEFT_ALT){
		Keyboard.releaseRaw(HID_KEY_ALT_LEFT);
	}else{
		Keyboard.release(x);
	}
}

void KbdInOut::key_releaseAll(void)
{
	Keyboard.releaseAll();
}


void setup()
{
	twkd=new(Twskbd);
}

void loop()
{
	twkd->main_loop(millis());
}

#endif

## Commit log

2024-05-14 add kicad files
    [lefthand_kbd2.kicad_pcb, lefthand_kbd2.kicad_sch]
2024-05-15 print key table
2024-05-19 use threading wait for infinite loop
2024-07-20 fix a problem after multi keys
    [twostkbd.py]
2024-08-03 fix missing relese events
    [twostkbd.py]
2024-08-18 use LED1 and LED2
2024-08-18 start testing with Arduino esp32-s3
2024-08-23 print key index
2024-08-25 check_possible_multikeys skips the first key with the gap
    [twostkbd.py]
2024-09-11 arduino version covers all the functions

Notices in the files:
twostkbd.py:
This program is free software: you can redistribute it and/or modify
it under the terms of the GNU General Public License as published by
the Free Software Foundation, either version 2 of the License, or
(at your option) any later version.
